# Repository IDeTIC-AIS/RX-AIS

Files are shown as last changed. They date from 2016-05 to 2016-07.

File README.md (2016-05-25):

# About this Repository

Within this repository you will find three directories: Firmware, Layout and Technical Notes. The file system repository allows access to files to develop an Automatic Identification System Modular Receiver.

**Firmware**

- aisRxController.ino =>  AIS Firmware  with Arduino language.
- nmea.c              =>  Library to implement the NMEA Protocol.
- nmea.h              =>  Header File.

**Layout**
- ais_rx1_v1.sch      =>  Schematic design in Eagle.
- ais_rx1_v1.brd      =>  Layout design in Eagle.
- AIS_RX_PCB.pdf      =>  Schematic and Layout (top and bottom layers).
- Connections.pdf     =>  Description of pin connections over prototype board.

**TechNotes**
- TechNote1.pdf       =>  RTL-SDR Sensitivity for AIS System.
- TechNote2.pdf       =>  DV-MEGA GMSK bitrate set-up for AIS System.

# Contact:
 
Francisco Cabrera, Nicolás Molina, Víctor Araña

francisco.cabrera@ulpgc.es

DSC-IDeTIC, Pabellón B Telecomunicaciones,

ULPGC, Campus de Tafira S/N,

Las Palmas de G.C. 35011, Spain

Miluse Tichavska

miluse.tichavska@marinetraffic.com

Exmile Solutions Limited (MarineTraffic),

1 Kings Avenue,

London N21 3NA, UK

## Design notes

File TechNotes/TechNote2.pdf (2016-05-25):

### Technical Note 2

### DV-MEGA GMSK bitrate set-up for AIS System

The DV-MEGA GMSK board [1] is a shield for Arduino, designed to perform GMSK modulation and demodulation tasks baseband. This board consists of a CMX589A GMSK modem [2, 3]. This chip includes a clock divider with three inputs: one input is connected to the output of the crystal oscillator (frequency Fin). This is the oscillation frequency, which for the DV-MEGA GMSK [2] device is 4.9152 MHz when this device is bought. The other inputs are logical statements that establish the value of division on the input frequency Fin (see Figure 1).

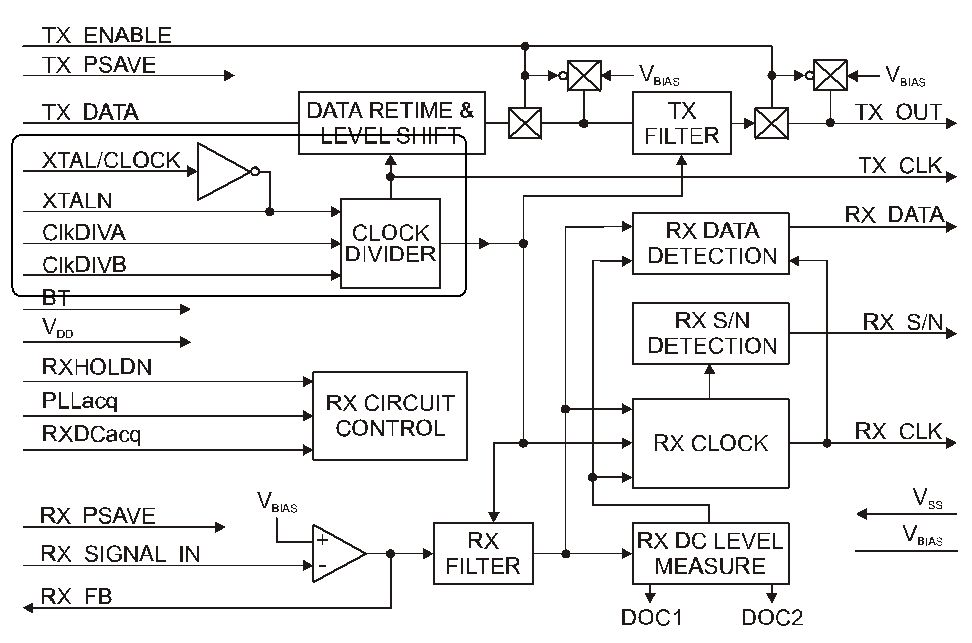
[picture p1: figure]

Figure 1. CMX589A subsystems

When a frequency Fin is introduced into Clock Divider with N division factor, the output frequency Fout is represented by this equation:

# Fooo = Fii

NN

The output frequency Fout coincides with the output bit rate CMX589A chip. Therefore, if a Fin = 5 MHz is introduced (for example), and the division ratio is N = 500, the output binary rate would be 1 Mbps. This is the basis operation of the subsystem clock divider in the CMX589A chip.

The DV-MEGA GMSK device includes a CMX589A chip, and the division clock inputs (ClkDIVA and ClkDIVB) are connected to the supply voltage. This means that ClkDIVB

ClkDIVA = 1 and = 1 (high logic level), so the division factor N = 1024 would be (see Figure 2).

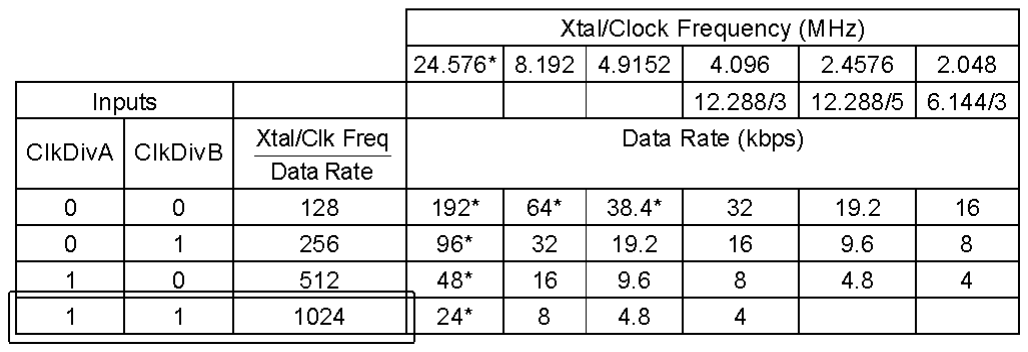
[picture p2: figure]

Figure 2. Clock Divisor configuration by CMX589A

Therefore, if the inputs are the clock divider to a fixed value, the only way to establish a data rate of 9.6 kbps (AIS system bitrate) is to change the crystal oscillator. This selection is based on the initial equation, so if N = 1024 and if we want to have an output frequency (or bit rate) such that Fout = 9.6 kbps, then:

# Fooo = Fii

NN

# → FFiiii = FFoooooo ⋅ NN = 9.6 ⋅ 103 ⋅ 1024 = 9.8304 MMMMMM

Thus, we have selected a 9.8304 MHz frequency for the crystal oscillator to obtain a bit rate of 9.6 kbps. So we had to change the 4.9152 MHz oscillator which is integrated on the external clock circuitry DV-MEGA GMSK (see Figure 3).

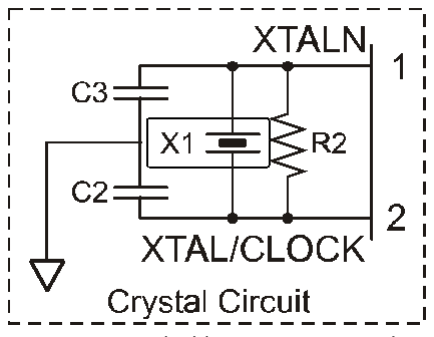
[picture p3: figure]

Figure 3. Extern clock circuit recommended by CMX589A and used by DV-MEGA GMSK
The rest of the circuit, such as R2 (1 MΩ) resistance or capacitors C2 and C3 (33 pF) are not modified because these values are valid for the bit rate of 9.6 kbps. This is another advantage of this solution, since it is not necessary to change other components of the DV-MEGA.

References:

[1] http://www.dvmega.auria.nl/GMSK_shield.html
[2] http://www.cmlmicro.com/products/CMX589A_Full-Duplex_GMSK_Modem/
[3] http://www.cmlmicro.com/assets/FX589DS.pdf

Contact:

Name: Francisco Cabrera, Nicolás Molina, Víctor Araña Email: francisco.cabrera@ulpgc.es
Address: DSC-IDeTIC, Pabellón B Telecomunicaciones, ULPGC, Campus de Tafira S/N, Las Palmas de G.C. 35011, Spain

Name: Miluše Tichavska
Email: miluse.tichavska@marinetraffic.com Address: Exmile Solutions Limited (MarineTraffic), 1 Kings Avenue,
London N21 3NA, UK

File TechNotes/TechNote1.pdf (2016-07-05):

### Technical Note 1

### RTL-SDR Sensitivity for AIS System

RTL-SDR [1] is a software defined radio that uses a DVB-T TV tuner dongle. Its manufacturer does not provide the necessary details to know the sensitivity for AIS System. In order to include this, a rather comprehensive study on this device would be required. As reference, the chip used by the RTL-SDR received is the RTL2832U. Its datasheet can be found on [2] from which the following parameters have been extracted.

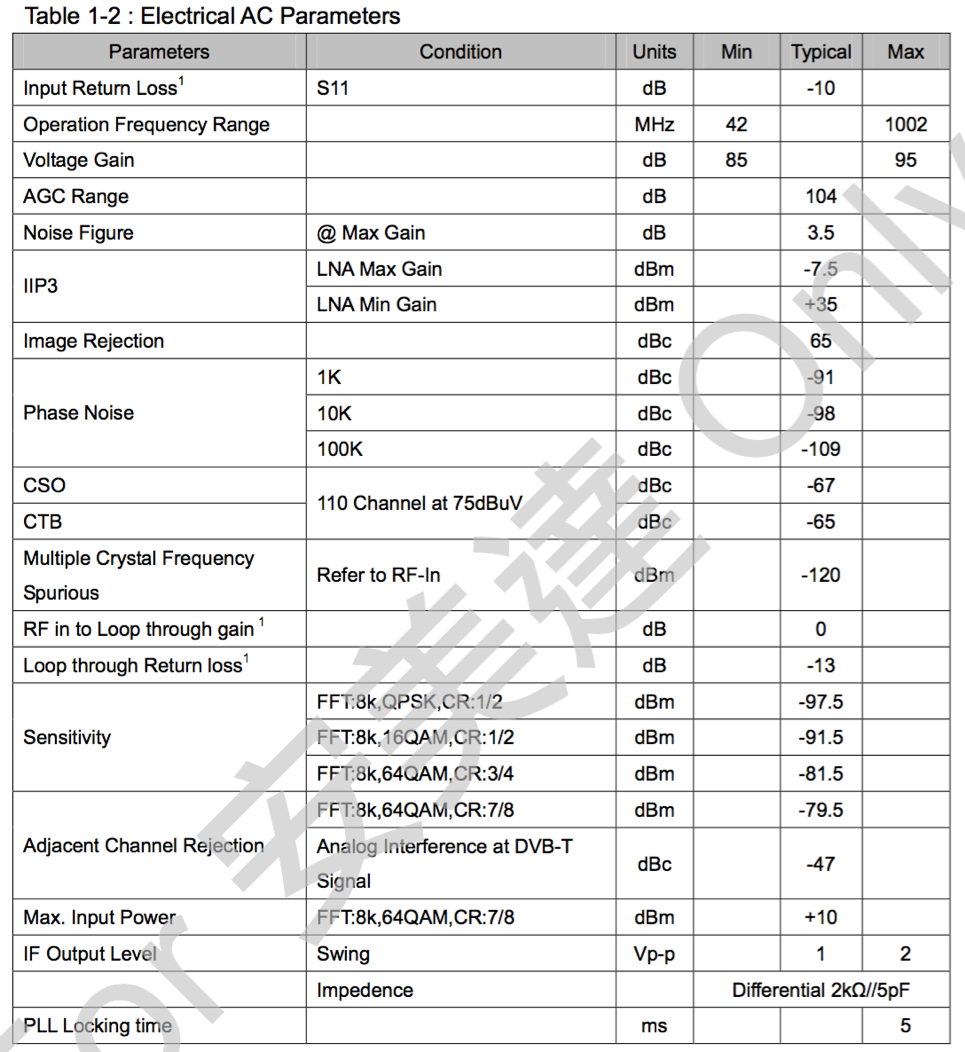
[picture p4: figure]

From the table, it can be observed, that its sensitivity value is given to enable DVB-T signal demodulation given that these devices were manufactured initially for this mentioned purpose. From the table we can read that for an FFT 8K QPSK, CR=1/2, the sensitivity value is of -97.5dBm and a Noise Floor (NF) of 3.5dB. The value of C/N is chosen from [3] in Table A.1.

Table A.1: Required C/N for Non-Hierarchical transmission to achieve a BER = 2 × 10-4 after the Viterbi decoder

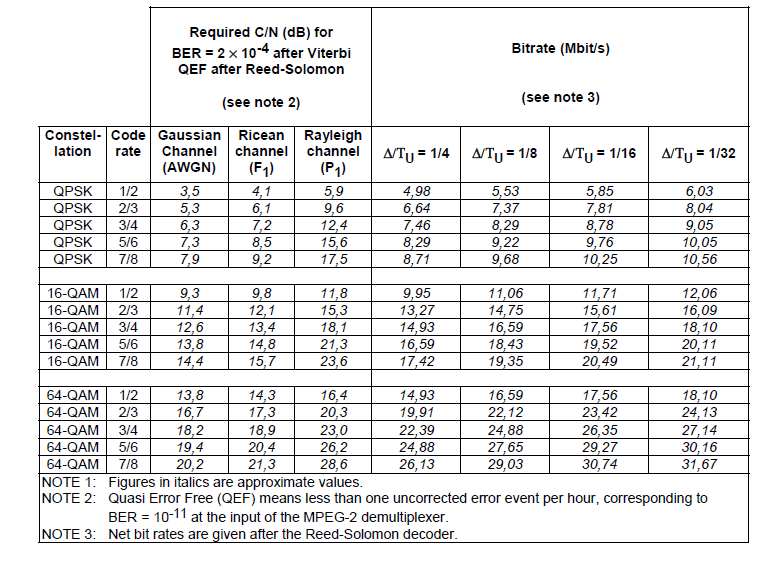
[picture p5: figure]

In this table, for the QPSK modulation, Code Rate of 1/2 and a Gaussian Channel (AWGN), the necessary value of C/N is of 3.5dB. The sensitivity can be calculated and have an estimative value throughout [4].

# SSSSSSSSSSSSSSSSSSSSSS(dddddd) = 10llllll10(KKKK ) + NNNN +

CC
NN + 30

Including the adequate values: K=1.38e-23 J/K, T= 290 K, B= 8 MHz, NF = 3.5 dB, C/N = 3.5 dB, a sensitivity = -97.9 dBm, is obtained. As it can be observed, the value is very close to the one indicated by the manufacturer. In this case, with a margin error of 0.4 dB.

The AIS system has a bandwidth of B=25 KHz and a relation Signal to Noise C/N = 10dB [5]. For this reason, and by using the same formula a sensitivity value = -116.5 dBm is obtained.

References:

[1] http://www.rtl-sdr.com/rtl-sdr-tutorial-cheap-ais-ship-tracking/
[2] http://rtlsdrblog.rtlsdrblog.netdna-cdn.com/wpcontent/uploads/2013/04/R820T_datasheet-Non_R-20111130_unlocked.pdf
[3] European Standard ETSI EN 300 744 “Digital Broadcasting (DVB); Framing structure, channel coding and modulation for digital terrestrial television”.
[4] Beasley J., Miller, G., Modern Electronic Communication (Eighth Edition), Ed. Phl.
[5] http://www.comarsystems.com/slr_300n.html

Contact:

Name: Francisco Cabrera, Nicolás Molina, Víctor Araña Email: francisco.cabrera@ulpgc.es
Address: DSC-IDeTIC, Pabellón B Telecomunicaciones, ULPGC, Campus de Tafira S/N, Las Palmas de G.C. 35011, Spain

Name: Miluše Tichavska
Email: miluse.tichavska@marinetraffic.com Address: Exmile Solutions Limited (MarineTraffic), 1 Kings Avenue,
London N21 3NA, UK

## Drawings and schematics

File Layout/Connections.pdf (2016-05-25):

## Wire clamp (clema)

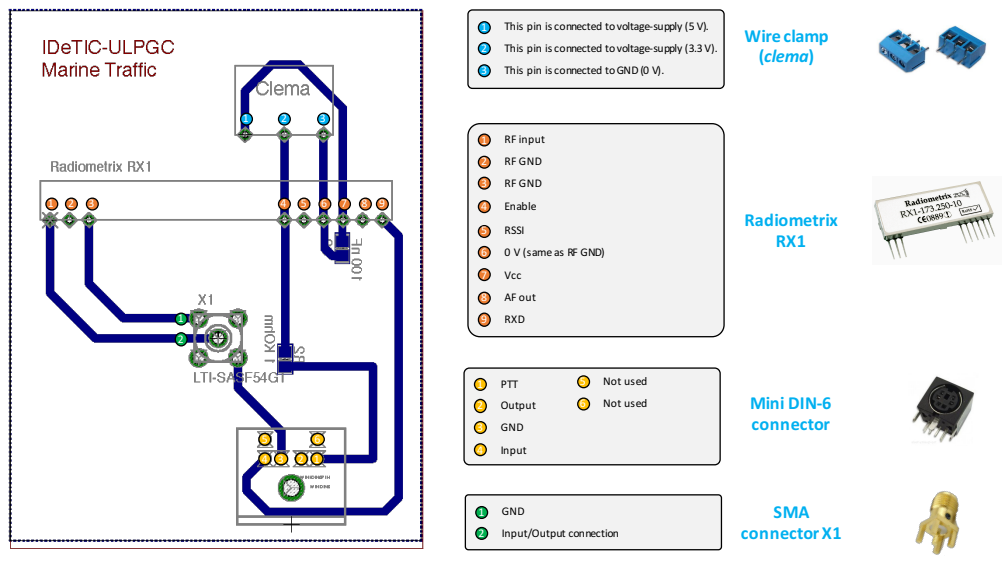
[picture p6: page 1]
Radiometrix RX1; RF input; RF GND; Enable; RSSI; 0 V (same as RF GND); Vcc; AF out; RXD; PTT; Output; GND; Input; Not used; Mini DIN-6; connector; SMA connector X1; Input/Output connection

This pin is connected to voltage-supply (5 V).
This pin is connected to voltage-supply (3.3 V).
This pin is connected to GND (0 V).

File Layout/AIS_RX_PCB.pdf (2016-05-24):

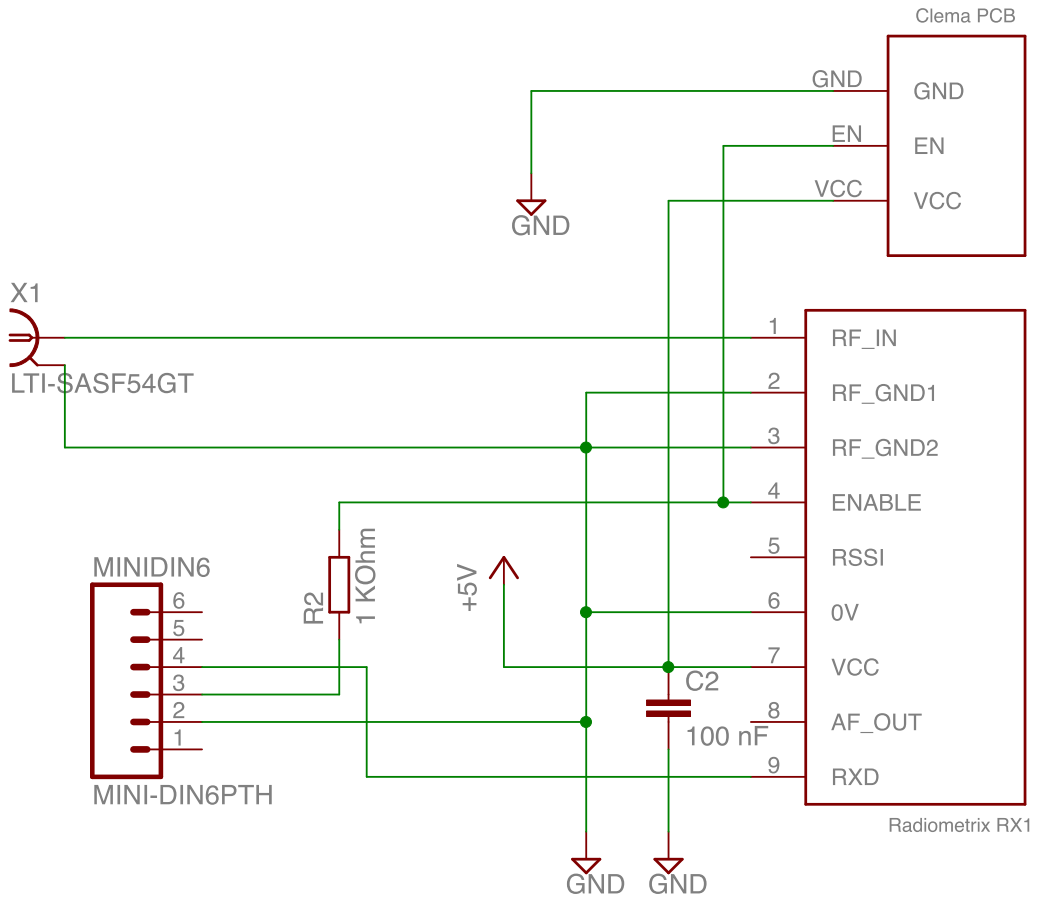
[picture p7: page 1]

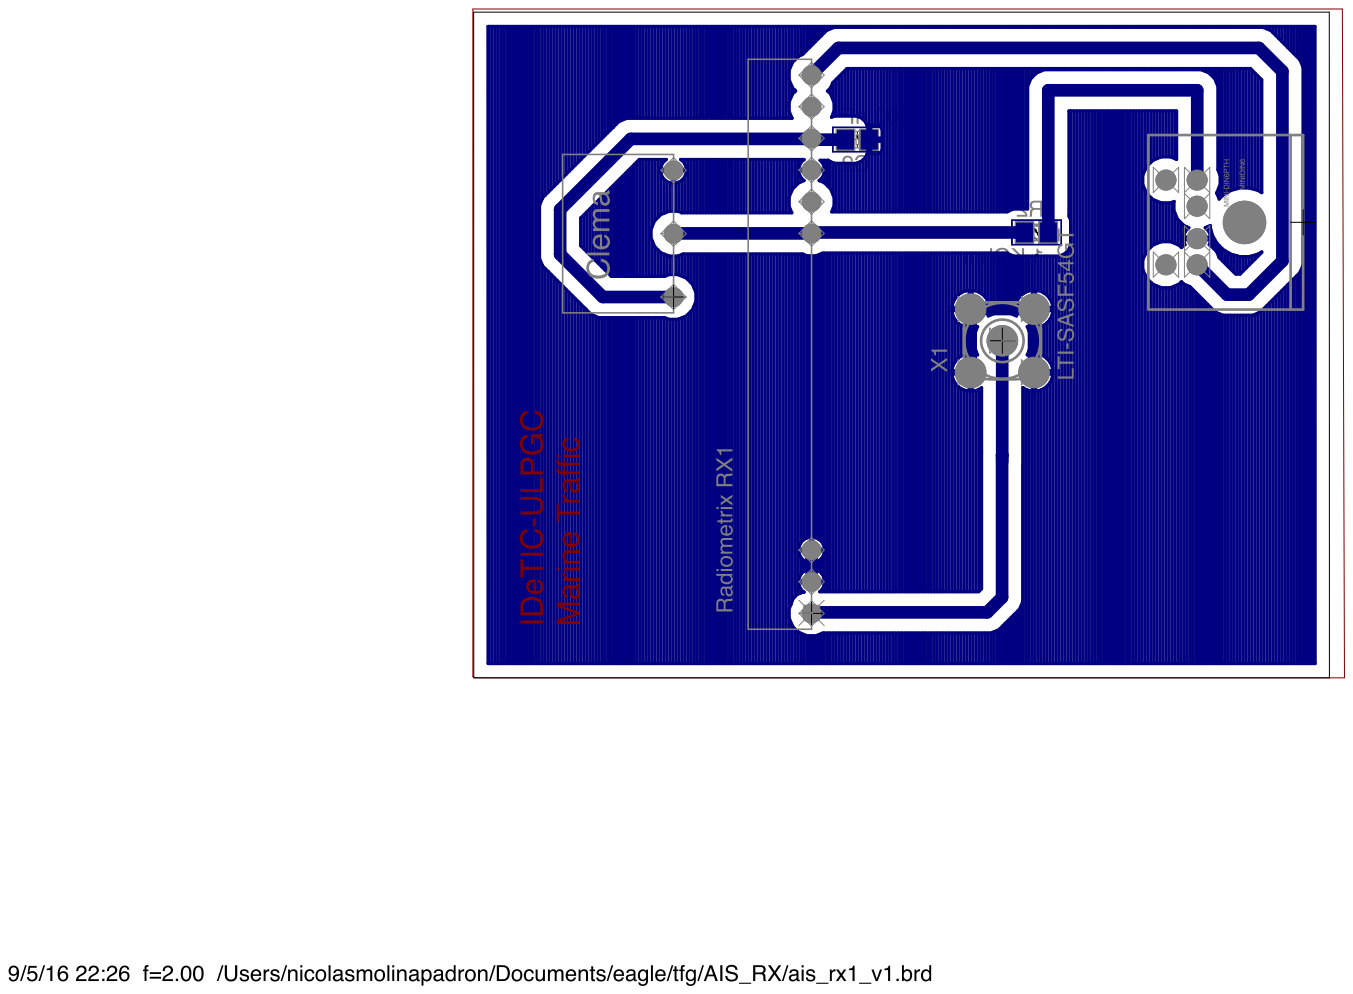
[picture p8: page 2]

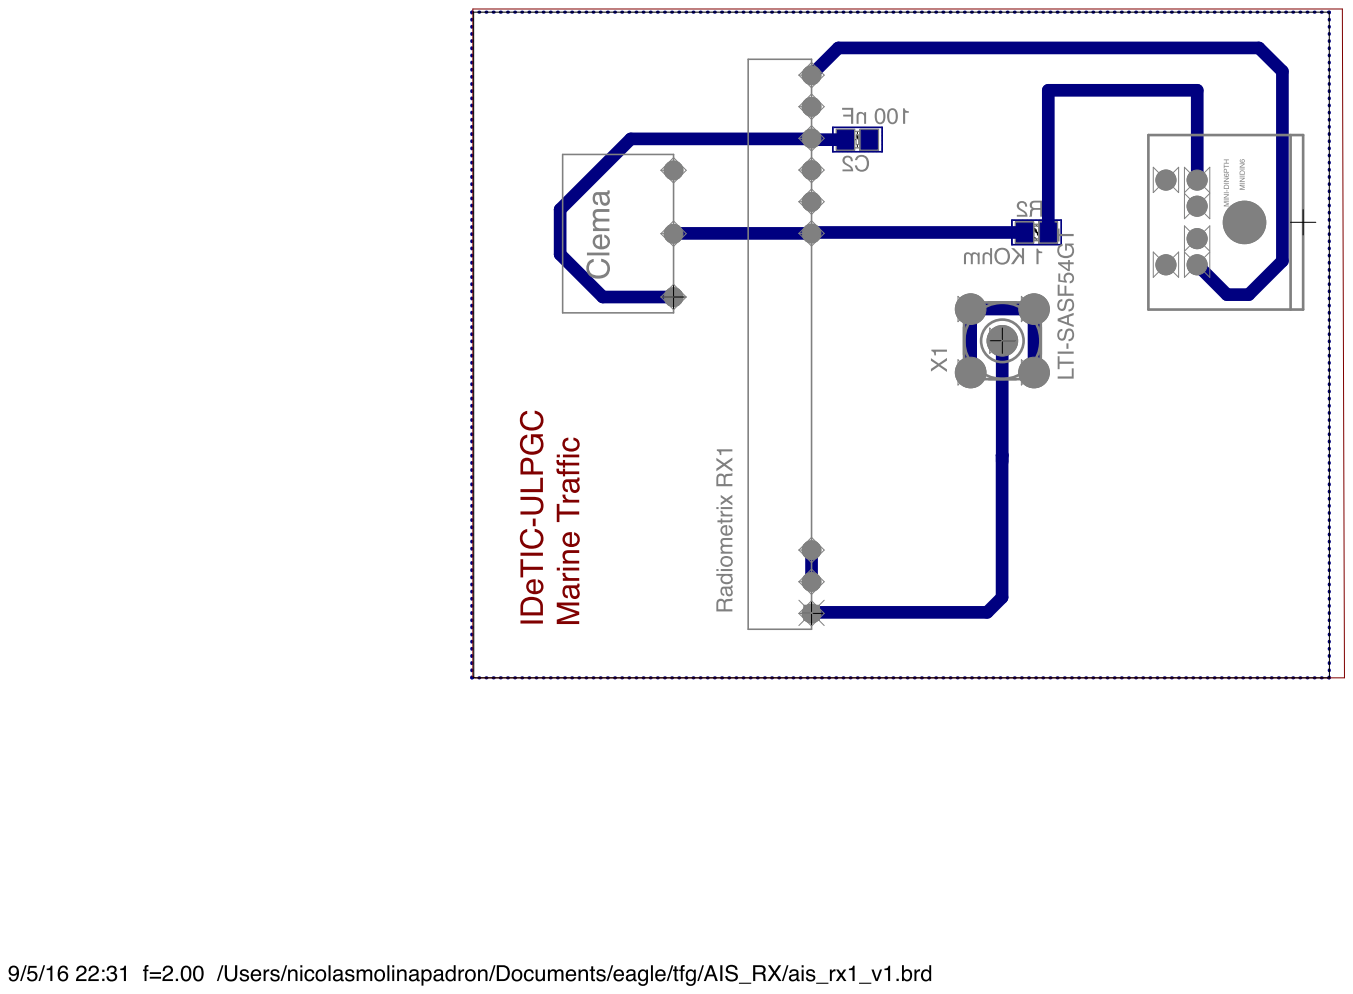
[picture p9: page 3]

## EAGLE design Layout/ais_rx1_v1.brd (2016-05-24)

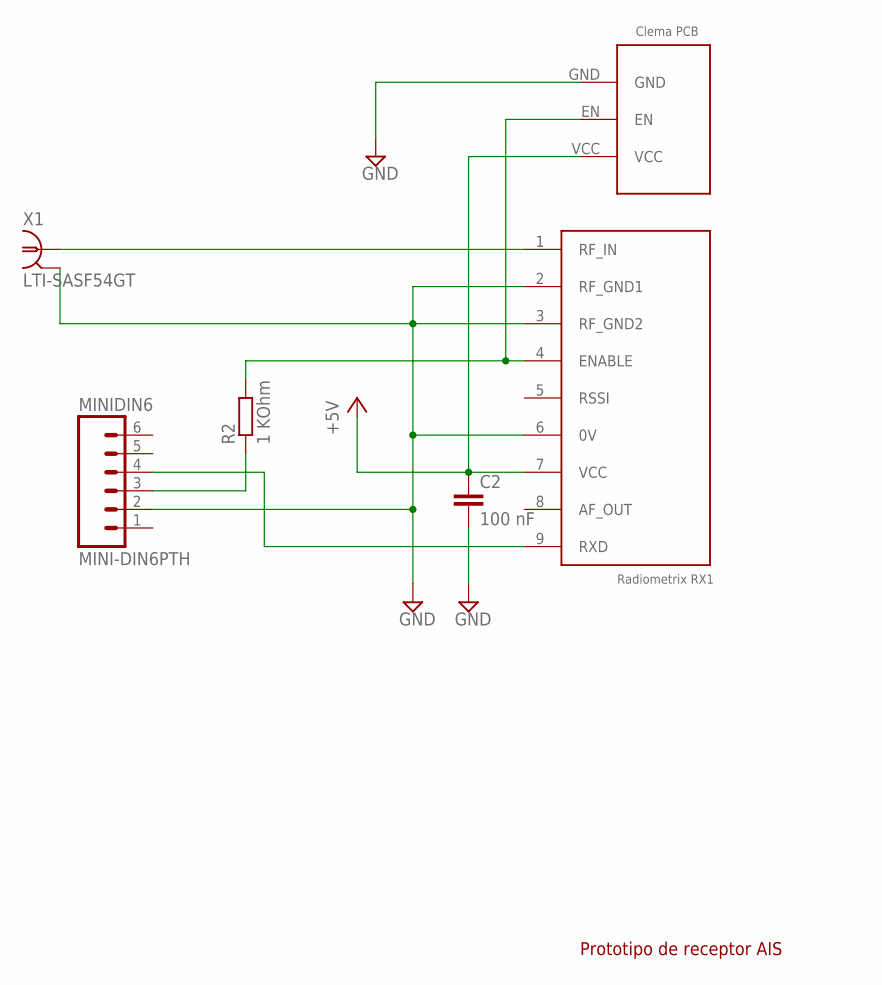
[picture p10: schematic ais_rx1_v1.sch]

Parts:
C2: 100 nF; C0805
CLEMAPCB1: CLEMA
MINIDIN6: MINI-DIN6PTH; MINI-DIN6
R2: 1 KOhm; R0805
RX1: RX1
X1: LTI-SASF54GT

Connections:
+5V: C2.1, CLEMAPCB1.VCC, RX1.7 (VCC)
GND: C2.2, CLEMAPCB1.GND, MINIDIN6.2, RX1.2 (RF_GND1), RX1.3 (RF_GND2), RX1.6 (0V), X1.2, X1.3 (2), X1.4 (2), X1.5 (2)
unnamed: RX1.1 (RF_IN), X1.1
unnamed: CLEMAPCB1.EN, R2.2, RX1.4 (ENABLE)
unnamed: MINIDIN6.4, RX1.9 (RXD)
unnamed: MINIDIN6.3, R2.1
RSSI: RX1.5 (RSSI)

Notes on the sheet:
Prototipo de receptor AIS

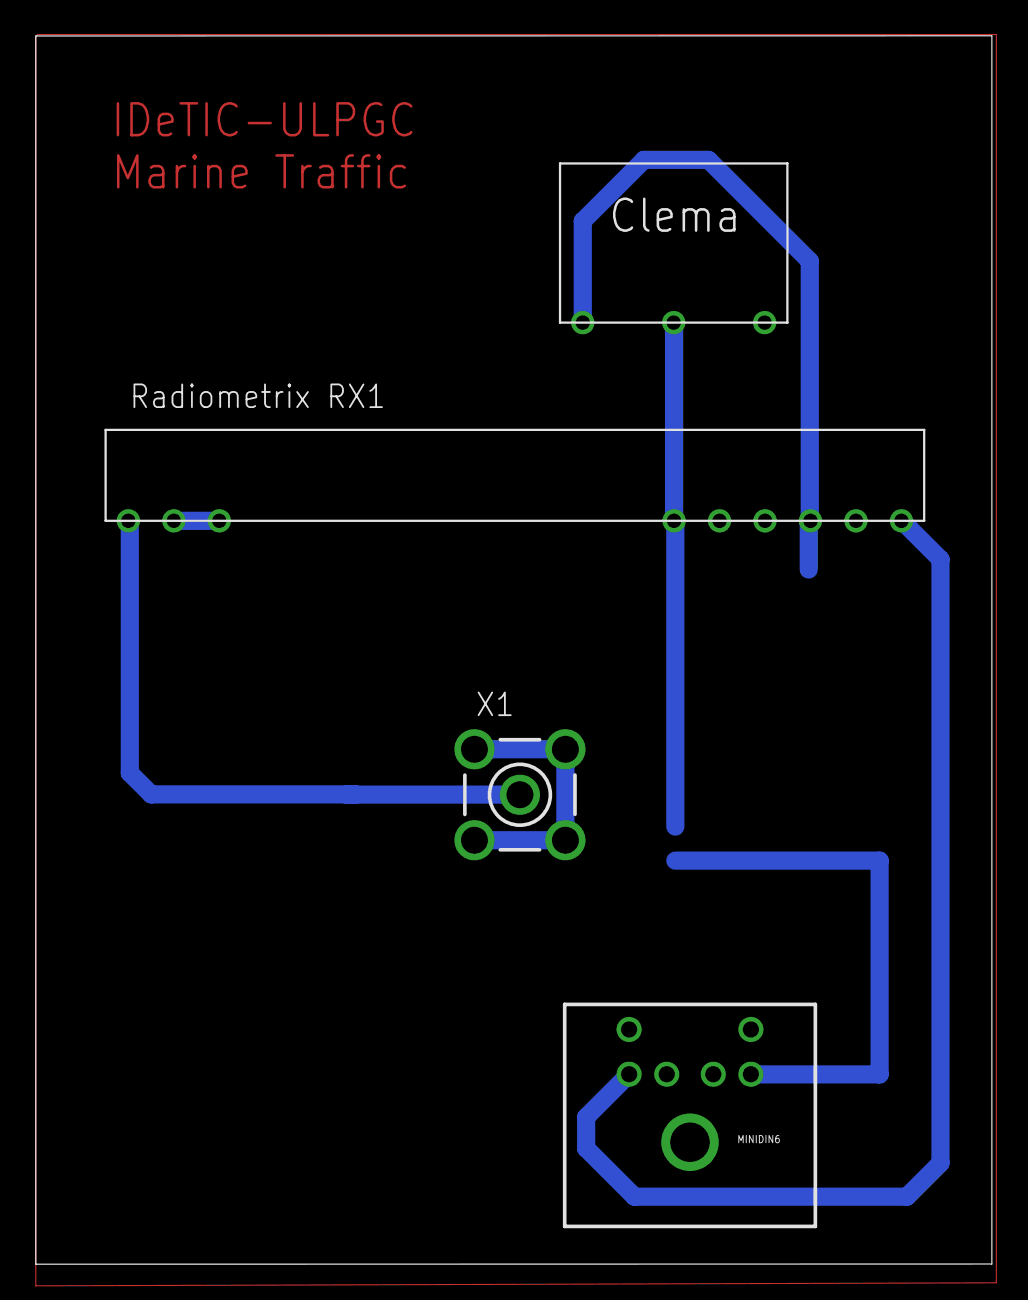
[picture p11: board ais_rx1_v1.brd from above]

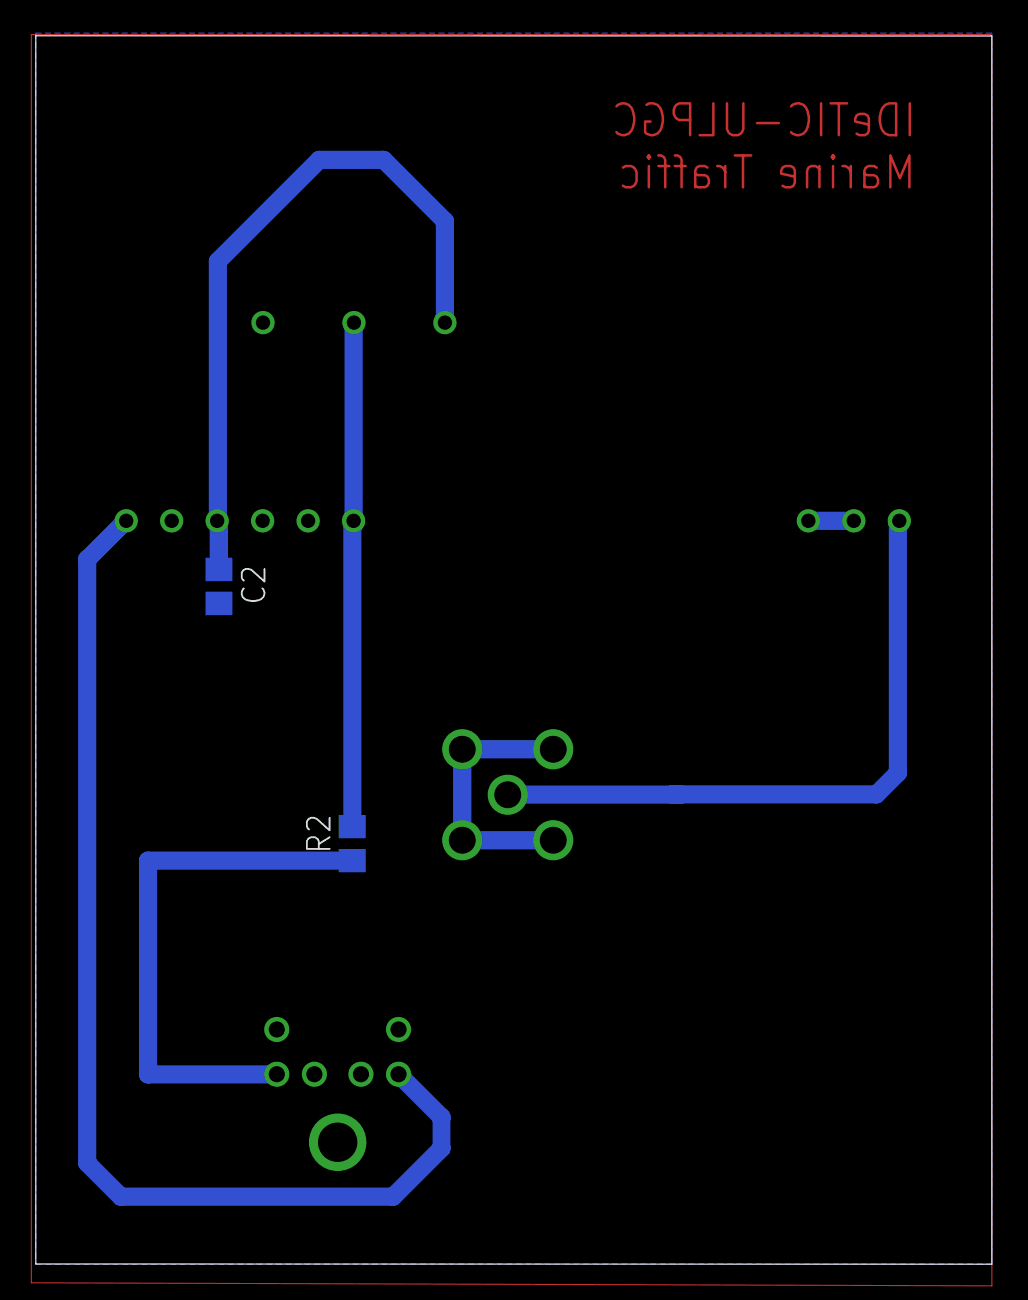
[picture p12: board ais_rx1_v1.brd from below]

Board: 2 copper layers, 53.4 x 68.6 mm, 6 parts (2 on the bottom side), 6 nets.

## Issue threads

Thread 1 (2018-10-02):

BOM?

hsiboy, 2018-10-02:
Gentlemen,

i'm very interested in this project, as the sensitivity of SDR dongle is not good for AIS reception.

I can not see a BOM. Does this require the DVmega modem + Arduino?

Thank you,

hsiboy, 2018-10-02:
Ah, nevermind.

I just found your paper. very interesting!

[https://agupubs.onlinelibrary.wiley.com/doi/pdf/10.1002/2015RS005895](https://agupubs.onlinelibrary.wiley.com/doi/pdf/10.1002/2015RS005895)

closing issue 😂

Closed 2018-10-02.

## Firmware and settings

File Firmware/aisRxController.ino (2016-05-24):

/* **************************************************************************
               UNIVERSIDAD DE LAS PALMAS DE GRAN CANARIA
       ESCUELA DE INGENIERIA DE TELECOMUNICACIONES Y ELECTRONICA
   
   Institution: Instituto para el Desarrollo Tecnologico y la Innovacion en
   Comunicaciones (IDeTIC)
   
   Summary: this code allows to receive AIS data by means of AIS prototype
   based to a DV-MEGA GMSK modem and Radiometrix RX1 which that had been
   developed by IDeTIC in 2015.
   
   Authors: Francisco Jose Cabrera Almeida
            Nicolas Molina Padron
 *************************************************************************** */

#include "nmea.c"

// definitions
#define   pinRXCLK       2
#define   pinTXCLK       3
#define   pinSN          4
#define   pinRXD         5
#define   pinTXD         6
#define   pinPTT         8
#define   pinPLLACQ      9
#define   pinLEDTX       10
#define   pinLEDCOS      11
#define   pinLEDPWR      12
#define   pinArduinoLED  13

// variable limits
#define   MAX_DATA       23
#define   HEADER         0x7E

// global variables
uint8_t rxdata;
uint8_t rxdataNRZI;
uint8_t rxdataNRZI_prev = 0;
uint8_t rxByte;
unsigned char rxHeader = 0;
unsigned char rxTail = 0;
uint8_t counterBitRx = 0;
uint8_t counterByteRx = 0;
unsigned char bufferRx[MAX_DATA];
int flagStartFrame = 0;
int flagRx = 0;

// initialization
void setup() {
  // serial port initialization (9600 bps)
  Serial.begin(9600);
  Serial.flush();
  // pin initialization
  pinMode(pinSN, INPUT);    
  pinMode(pinRXD, INPUT);    
  pinMode(pinTXD, OUTPUT);
  pinMode(pinLEDTX, OUTPUT);    
  pinMode(pinLEDCOS, OUTPUT);
  pinMode(pinLEDPWR, OUTPUT);
  pinMode(pinPTT, OUTPUT);
  pinMode(pinPLLACQ, OUTPUT);
  // ISR initialization
  attachInterrupt(0, rxISR, FALLING);
}

// main program
void loop() {
  // if the end of data frame is reached, 
  // stored bytes are converted to NMEA format and sent by Serial port
  if(flagRx) {
    
    NMEA_Send(bufferRx, MAX_DATA);       
//    for(int k=0; k<MAX_DATA; k++) {
//      delay(10);
//      Serial.write(bufferRx[k]);
//    }
    // variables reset
    flagRx = 0;
    rxHeader = 0;
    rxTail = 0;
    // ISR is activated again
    attachInterrupt(0, rxISR, FALLING);
  }
}

// receiver ISR (Interrupt Service Routine)
void rxISR() {
  // store bits which has been read by means of RXD pin
  rxdata = digitalRead(pinRXD);
  // NRZI decode
  if(rxdataNRZI == HIGH) {
    rxdata = rxdataNRZI_prev ^ rxdataNRZI;
  } else {
    rxdata = rxdataNRZI_prev;
  }
  rxdataNRZI_prev = rxdataNRZI;
  // evaluation of AIS frame fields:
  // case 0 -> training sequence (0x55-0x55-0x55)
  // case 1 -> header (0x7E)
  // case 2 -> data and CRC field
  switch(flagStartFrame) {
    case 0:
      rxHeader = (rxHeader << 1) | rxdata;
      if(rxHeader == 0x7E) {
        flagStartFrame = 1;
      }
      break;
    case 1:
      rxByte = (rxByte << 1) | rxdata;
      if(counterBitRx >= 7) {
        bufferRx[counterByteRx] = rxByte;
        counterByteRx++;
        counterBitRx = 0;
        rxByte = 0;
        if(counterByteRx >= MAX_DATA) {
          flagStartFrame = 2;
        }
      } else {
        counterBitRx++;
      }
      break;
    case 2:
      rxTail = (rxTail << 1) | rxdata;
      if(counterBitRx >= 7) {
        flagStartFrame = 0;
        counterBitRx = 0;
        counterByteRx = 0;
        detachInterrupt(0);
        flagRx = 1;
      } else {
        counterBitRx++;
      }
      break;
  }
}

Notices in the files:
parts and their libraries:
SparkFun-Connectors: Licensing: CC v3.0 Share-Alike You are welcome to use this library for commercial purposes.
